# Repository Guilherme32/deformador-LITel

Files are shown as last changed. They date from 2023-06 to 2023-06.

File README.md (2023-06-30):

# Deformador do LITel

Esse repositório guarda o que foi desenvolvido de parte eletrônica / de código
do deformador do LITel.

# Informações

O deformador é um equipamento construído para aplicar uma deformação controlada
a uma placa de teste. A placa é afixada em uma extremidade, enquanto que a
outra é conectada a um cabo de aço que pode fazer uma força para baixo,
deformando o material com uma flecha. Um dinamômetro entre a placa e o cabo de
aço mede a força constantemente, para que o sistema possa ser usado para
calibração de sensores. O cabo de aço é puxado por um sistema com um motor de
passo e um fuso, controlado por um esp8266 através de duas interfaces
possíveis.

Embora o sistema tenha a possibilidade de visualização do movimento do fuso do
motor, é recomendado que se use apenas a força lida no dinamômetro para
calibração de sensores. Isso se dá porque a distância percorrida no fuso não
é igual à distância da flecha na placa, por conta dos componentes que estão no
meio do caminho.

# Interface Física

A interface mais simples de se usar é a física, composta de 7 botões. Com o
lado dos botões para cima, e o conector à esquerda, a função dos botões são,
seguindo da esquerda para a direita:

- Botão 1: Recua 5cm (alivia a carga);
- Botão 2: Recua 5mm (alivia a carga);
- Botão 3: Recua 1mm (alivia a carga);
- Botão 4: Interrompe o movimento;
- Botão 5: Avança 1mm (aumenta a carga);
- Botão 6: Avança 5mm (aumenta a carga);
- Botão 7: Avança 5cm (aumenta a carga);

Caso os botões sejam segurados, os comandos serão continuamente repetidos,
sendo que os valores são atualizados a partir do atual. Dessa forma, o sistema
irá iniciar o movimento ao pressionar o botão, e irá se mover pelo valor do
botão após ser soltado.

> Por exemplo, se o botão 3 for segurado por 2 segundos, e então solto, o
> sistema irá recuar continuamente por 2 segundos, e após isso ainda irá recuar
> mais 1mm.

Os botões mais extremos movem a flecha por valores consideravelmente grandes, e
foram feitos com o objetivo de colocar um alvo distante e de que os comandos
sejam interrompidos manualmente.

Com essa interface, não há como saber a distância percorrida no fuso do motor.

# Interface Web

Para o uso da interface web, é necessário o uso de um dispositivo que esteja
conectado à mesma rede local do esp8266 e seja capaz de renderizar páginas web
(HTML, CSS e JS). O esp possui a função de ponto de acesso, permitindo a
que o dispositivo se conecte diretamente a ele, caso possua conectividade WiFi.

## Ponto de Acesso (Access Point)

As credenciais de acesso do modo de ponto de acesso são as seguintes:

> SSID: deformador-litel
> Senha: 787Cu7kg

Nesse modo, o programa pode ser acessado através do ip:

> ip: 192.168.4.1

## Modo Estação (Station)

O esp também pode se conectar a uma rede externa. Isso aumenta a confiabilidade
do sistema, porque o ponto de acesso do esp não é muito estável. Para que ele
se conecte, é necessário que primeiro o dispositivo acesse o programa pelo
ponto de acesso, e então configure as credenciais da rede externa pela página
de conexão. Na página de conexão é possível ver o status (se conseguiu
conectar) e o endereço de ip.

Com o dispositivo conectado à mesma rede externa, o endereço ip do esp deverá
ser utilizado para acessar a aplicação.

> O esp tentará se conectar à última rede configurada sempre que for ligado.

## Páginas

### Página Principal

A página principal serve apenas como entrada à interface. Ela permite acesso às
outras páginas do sistema, e também tem o link do repositório no GitHub.

> Todas as páginas possuem os mesmos links presentes nessa.

### Conexão

Essa página mostra as informações de conexão (SSID, senha, ip), e permite mudar
as credenciais da rede a ser acessada pelo modo estação. Também indica se o
modo de estação está conectado devidamente.

### Controle

Essa página é a que permite a interface principal do sistema. Através daqui é
possível visualizar a posição atual do motor, o deslocamento correspondente no
fuso, e também enviar novos comandos para o sistema.

Os componentes importantes da página são:

- Comandos: É possível enviar dois comandos para o sistema:
  - Deslocar: Envia uma nova posição alvo para o deslocamento. Esse comando não
              é cumulativo, o valor enviado é o alvo, não um valor a mover;
  - Encontrar zero: Envia o comando de reset de zero. O sistema entrará na
                    sequência de detecção, não podendo receber outros comandos
                    e recuando (aliviando a carga) até que encontrar o sensor
                    de fim de curso;
- Informações: Algumas informações são dispostas no centro da página:
  - Progresso: Uma barra cresce da esquerda para a direita, indicando o
               progresso do último comando;
  - Estado: O estado do sistema, que pode ser "movendo", "parado" ou
            "procurando zero"
  - Posição: A posição e correspondente deslocamento atuais no fuso do motor.

> !! O DESLOCAMENTO NÃO DEVE SER USADO PARA CALIBRAÇÃO !! É possível calcular a
> deformação da placa a partir da flecha, mas não é trivial calcular a flecha
> a partir do deslocamento do fuso. Os deslocamentos não serão iguais, porque
> o cabo de aço, o dinamômetro e outros componentes no meio do caminho se
> deformam

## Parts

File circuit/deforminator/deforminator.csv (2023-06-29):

Source: | D:\espstuff\8266\msys32\home\guilh\esp8266\deforminator\circuit\deforminator\deforminator.kicad_sch
Date: | 14/06/2023 17:54:08
Tool: | Eeschema (6.0.5)
Generator: | D:\Programs\KiCad\6.0\bin\scripting\plugins/bom_csv_grouped_by_value.py
Component Count: | 21
Individual Components:
Item | Qty | Reference(s) | Value | LibPart | Footprint | Datasheet
 |  | A1 | Pololu_Breakout_DRV8825 | Driver_Motor:Pololu_Breakout_DRV8825 | Module:Pololu_Breakout-16_15.2x20.3mm | https://www.pololu.com/product/2982
 |  | D1 | LED | Device:LED | LED_THT:LED_D3.0mm_Clear | ~
 |  | D2 | LED | Device:LED | LED_THT:LED_D3.0mm_Clear | ~
 |  | D3 | LED | Device:LED | LED_THT:LED_D3.0mm_Clear | ~
 |  | J1 | Conn_01x04_Male | Connector:Conn_01x04_Male | Connector_PinHeader_2.54mm:PinHeader_1x04_P2.54mm_Vertical | ~
 |  | J2 | Conn_01x02_Male | Connector:Conn_01x02_Male | Connector_PinHeader_2.54mm:PinHeader_1x02_P2.54mm_Vertical | ~
 |  | J3 | Conn_01x02_Male | Connector:Conn_01x02_Male | Connector_PinHeader_2.54mm:PinHeader_1x02_P2.54mm_Vertical | ~
 |  | J4 | Conn_01x02_Male | Connector:Conn_01x02_Male | Connector_PinHeader_2.54mm:PinHeader_1x02_P2.54mm_Vertical | ~
 |  | J5 | Conn_01x02_Male | Connector:Conn_01x02_Male | Connector_PinHeader_2.54mm:PinHeader_1x02_P2.54mm_Vertical | ~
 |  | R1 | R | Device:R | Resistor_THT:R_Axial_DIN0207_L6.3mm_D2.5mm_P7.62mm_Horizontal | ~
 |  | R2 | R | Device:R | Resistor_THT:R_Axial_DIN0207_L6.3mm_D2.5mm_P7.62mm_Horizontal | ~
 |  | R3 | R | Device:R | Resistor_THT:R_Axial_DIN0207_L6.3mm_D2.5mm_P7.62mm_Horizontal | ~
 |  | R4 | R | Device:R | Resistor_THT:R_Axial_DIN0207_L6.3mm_D2.5mm_P7.62mm_Horizontal | ~
 |  | R5 | R | Device:R | Resistor_THT:R_Axial_DIN0207_L6.3mm_D2.5mm_P7.62mm_Horizontal | ~
 |  | R6 | R | Device:R | Resistor_THT:R_Axial_DIN0207_L6.3mm_D2.5mm_P7.62mm_Horizontal | ~
 |  | R7 | R | Device:R | Resistor_THT:R_Axial_DIN0207_L6.3mm_D2.5mm_P7.62mm_Horizontal | ~
 |  | R8 | R | Device:R | Resistor_THT:R_Axial_DIN0207_L6.3mm_D2.5mm_P7.62mm_Horizontal | ~
 |  | R9 | R | Device:R | Resistor_THT:R_Axial_DIN0207_L6.3mm_D2.5mm_P7.62mm_Horizontal | ~
 |  | SWreset1 | SW_Push | Switch:SW_Push | Button_Switch_THT:SW_PUSH_6mm | ~
 |  | SWreset2 | SW_Push | Switch:SW_Push | Button_Switch_THT:SW_PUSH_6mm | ~
 |  | U1 | ESP-12E | RF_Module:ESP-12E | RF_Module:ESP-12E | http://wiki.ai-thinker.com/_media/esp8266/esp8266_series_modules_user_manual_v1.1.pdf
Collated Components:
Item | Qty | Reference(s) | Value | LibPart | Footprint | Datasheet
1 | 1 | A1 | Pololu_Breakout_DRV8825 | Driver_Motor:Pololu_Breakout_DRV8825 | Module:Pololu_Breakout-16_15.2x20.3mm | https://www.pololu.com/product/2982
2 | 3 | D1, D2, D3 | LED | Device:LED | LED_THT:LED_D3.0mm_Clear | ~
3 | 1 | J1 | Conn_01x04_Male | Connector:Conn_01x04_Male | Connector_PinHeader_2.54mm:PinHeader_1x04_P2.54mm_Vertical | ~
4 | 4 | J2, J3, J4, J5 | Conn_01x02_Male | Connector:Conn_01x02_Male | Connector_PinHeader_2.54mm:PinHeader_1x02_P2.54mm_Vertical | ~
5 | 9 | R1, R2, R3, R4, R5, R6, R7, R8, R9 | R | Device:R | Resistor_THT:R_Axial_DIN0207_L6.3mm_D2.5mm_P7.62mm_Horizontal | ~
6 | 2 | SWreset1, SWreset2 | SW_Push | Switch:SW_Push | Button_Switch_THT:SW_PUSH_6mm | ~
7 | 1 | U1 | ESP-12E | RF_Module:ESP-12E | RF_Module:ESP-12E | http://wiki.ai-thinker.com/_media/esp8266/esp8266_series_modules_user_manual_v1.1.pdf

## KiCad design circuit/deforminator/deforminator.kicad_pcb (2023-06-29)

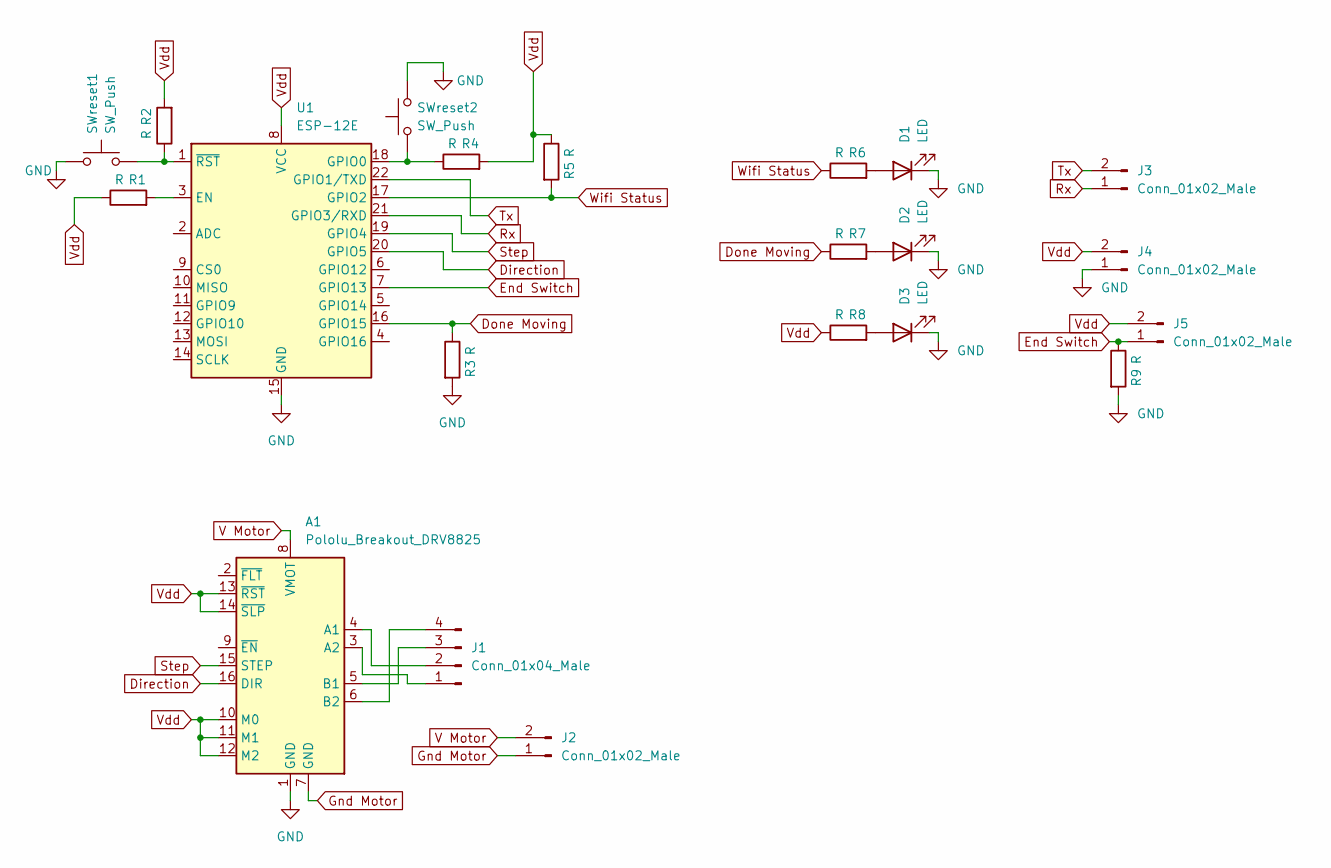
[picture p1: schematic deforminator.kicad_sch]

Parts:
A1: Pololu_Breakout_DRV8825; Pololu_Breakout-16_15.2x20.3mm
D1, D2, D3: LED; LED_D3.0mm_Clear
J1: Conn_01x04_Male; PinHeader_1x04_P2.54mm_Vertical
J2, J3, J4, J5: Conn_01x02_Male; PinHeader_1x02_P2.54mm_Vertical
R1, R2, R3, R4, R5, R6, R7, R8, R9: R; R_Axial_DIN0207_L6.3mm_D2.5mm_P7.62mm_Horizontal
SWreset1, SWreset2: SW_Push; SW_PUSH_6mm
U1: ESP-12E

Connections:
Direction: A1.16 (DIR), U1.20 (GPIO5)
Done Moving: R3.1, R7.1, U1.16 (GPIO15)
End Switch: J5.1, R9.1, U1.7 (GPIO13)
GND: A1.1 (GND), D1.1 (K), D2.1 (K), D3.1 (K), J4.1, R3.2, R9.2, SWreset1.1, SWreset2.2, U1.15 (GND)
Gnd Motor: A1.7 (GND), J2.1
unnamed: A1.3 (A2), J1.1
unnamed: A1.4 (A1), J1.2
unnamed: A1.5 (B1), J1.3
unnamed: A1.6 (B2), J1.4
unnamed: D3.2 (A), R8.2
unnamed: R1.2, U1.3 (EN)
unnamed: R2.1, SWreset1.2, U1.1 (~RST)
unnamed: R4.1, SWreset2.1, U1.18 (GPIO0)
unnamed: D1.2 (A), R6.2
unnamed: D2.2 (A), R7.2
Rx: J3.1, U1.21 (GPIO3/RXD)
Step: A1.15 (STEP), U1.19 (GPIO4)
Tx: J3.2, U1.22 (GPIO1/TXD)
V Motor: A1.8 (VMOT), J2.2
Vdd: A1.10 (M0), A1.11 (M1), A1.12 (M2), A1.13 (~RST), A1.14 (~SLP), J4.2, J5.2, R1.1, R2.2, R4.2, R5.1, R8.1, U1.8 (VCC)
Wifi Status: R5.2, R6.1, U1.17 (GPIO2)

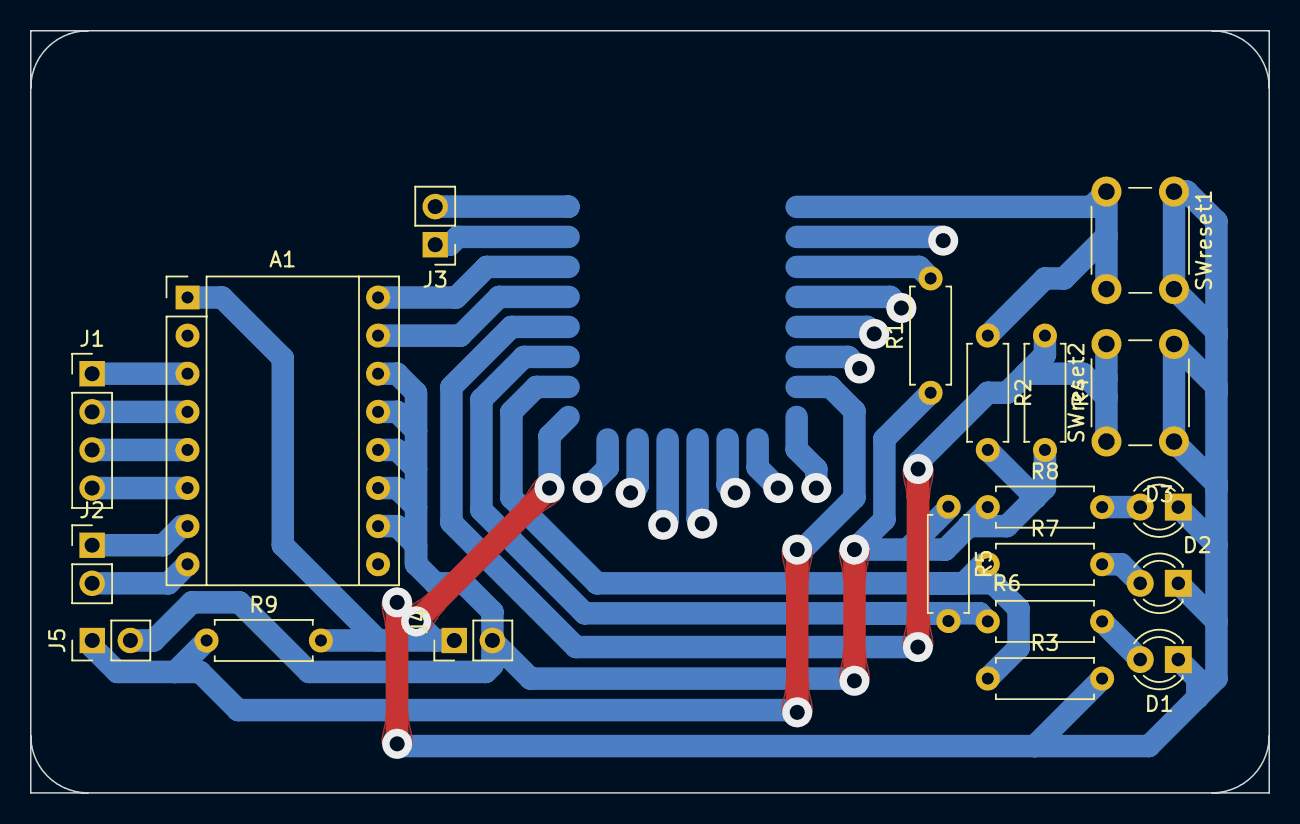
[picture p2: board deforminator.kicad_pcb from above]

Board: 2 copper layers, 82.6 x 50.8 mm, 21 parts (1 on the bottom side), 21 nets.

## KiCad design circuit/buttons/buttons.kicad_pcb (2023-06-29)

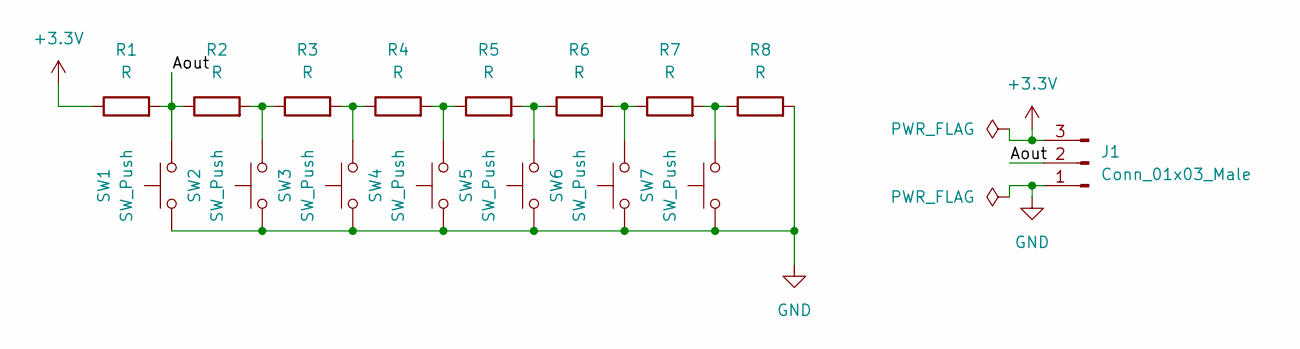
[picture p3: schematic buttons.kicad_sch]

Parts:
J1: Conn_01x03_Male; PinHeader_1x03_P2.54mm_Vertical
R1, R2, R3, R4, R5, R6, R7, R8: R; R_Axial_DIN0207_L6.3mm_D2.5mm_P7.62mm_Horizontal
SW1, SW2, SW3, SW4, SW5, SW6, SW7: SW_Push; SW_PUSH-12mm

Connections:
+3V3: J1.3, R1.1
/Aout: J1.2, R1.2, R2.1, SW1.2
GND: J1.1, R8.2, SW1.1, SW2.1, SW3.1, SW4.1, SW5.1, SW6.1, SW7.1
unnamed: R2.2, R3.1, SW2.2
unnamed: R3.2, R4.1, SW3.2
unnamed: R4.2, R5.1, SW4.2
unnamed: R5.2, R6.1, SW5.2
unnamed: R6.2, R7.1, SW6.2
unnamed: R7.2, R8.1, SW7.2

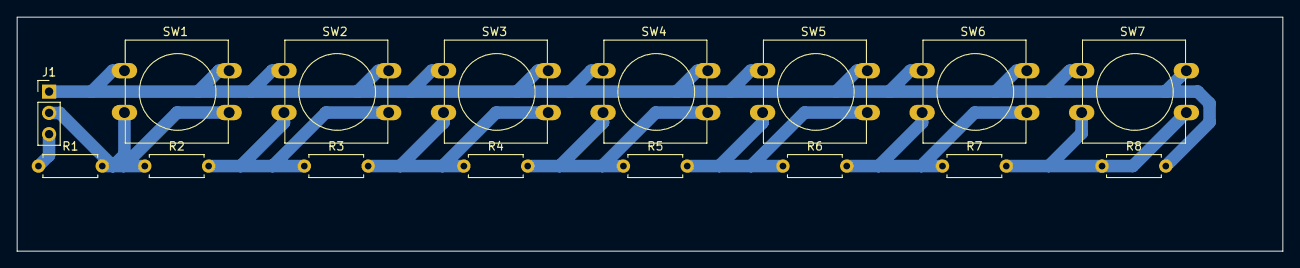
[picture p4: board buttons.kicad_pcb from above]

Board: 2 copper layers, 151.1 x 27.9 mm, 16 parts (0 on the bottom side), 9 nets.

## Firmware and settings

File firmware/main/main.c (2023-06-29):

/* Deformador do LITel
* O controle e interface do sistema foram desenvolvidos sobre um esp8266, e
* aqui esta o codigo do seu firmware. Mais informacoes do sistema podem ser
* obtidas no github: https://github.com/Guilherme32/deformador-LITel
*/


#include <stdio.h>
#include "freertos/FreeRTOS.h"
#include "freertos/task.h"
#include "esp_system.h"
#include "esp_spi_flash.h"
#include "esp_log.h"

#include "wifi.h"
#include "server.h"
#include "storage_spiffs.h"
#include "controller.h"
#include "serial_comm.h"


void app_main()
{
    // Some system info print -------------------------------------------------
    print_header();
    ESP_LOGI("STARTUP", "Starting up the system");

    // Modules init -----------------------------------------------------------
    wifi_init();
    spiffs_init();
    server_init(10);
    controller_init();
    serial_comm_init();

    // Linking modules --------------------------------------------------------
    add_command(netinfo_command, netinfo_command_help);

    // Starting modules tasks -------------------------------------------------
    xTaskCreate(wifi_led_task,
        "wifi_led_task",
        2*configMINIMAL_STACK_SIZE,
        NULL,
        10,
        NULL);

    xTaskCreate(serial_comm_task,
        "serial_task",
        2*configMINIMAL_STACK_SIZE,
        NULL,
        10,
        NULL);

    xTaskCreate(poll_buttons,
        "poll_buttons",
        2*configMINIMAL_STACK_SIZE,
        NULL,
        10,
        NULL);

}

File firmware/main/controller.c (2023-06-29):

#include "controller.h"
#include "helpers.h"

// Internal definitions ---------------------------------------------------------------------------

#define END_SWITCH_PIN 13
#define INPUT_PINS_FLAG (1ULL << END_SWITCH_PIN)

#define DIRECTION_PIN 5
#define STEP_PIN 4
#define DONE_MOVING_PIN 15
#define OUTPUT_PINS_FLAG   ( (1ULL << DIRECTION_PIN) \
                           | (1ULL << DONE_MOVING_PIN) \
                           | (1ULL << STEP_PIN) )

// Period = 400 us, pps = 2500
#define STEP_HALF_PERIOD_US 200

#define CONTROLLER_TAG "CONTROLLER"

#define DIR_PULL 0
#define DIR_PUSH 1

#define MULTISAMPLING 16

// ------------------------------------------------------------------------------------------------

static int target = 0;
static int real_position = 0;
static bool done_moving = 0;

static bool finding_zero = false;
static bool step_pulse_value = false;

// ------------------------------------------------------------------------------------------------

void step_to_find_zero() {
    if (step_pulse_value == 1) {
        if (gpio_get_level(END_SWITCH_PIN) == 1) {
            target = 0;
            real_position = 0;
            finding_zero = false;
            hw_timer_enable(false);
        }

        step_pulse_value = 0;
    } else {
        gpio_set_level(DIRECTION_PIN, DIR_PUSH);
        step_pulse_value = 1;
    }

    gpio_set_level(STEP_PIN, step_pulse_value);
}

void try_step(void* arg) {
    if (finding_zero) {
        step_to_find_zero();
        return;
    }

    if (step_pulse_value == 1) {
        if (target == real_position) {
            hw_timer_enable(false);
            done_moving = true;
            gpio_set_level(DONE_MOVING_PIN, 1);
            return;
        }

        step_pulse_value = 0;
    } else {
        if (target > real_position) {
            gpio_set_level(DIRECTION_PIN, DIR_PULL);
            real_position ++;
        } else {
            gpio_set_level(DIRECTION_PIN, DIR_PUSH);
            real_position --;
        }

        step_pulse_value = 1;
    }

    gpio_set_level(STEP_PIN, step_pulse_value);
}

// Buttons ---------------------------------------
void buttons_init() {
    adc_config_t adc_config;
    adc_config.mode = ADC_READ_TOUT_MODE;
    adc_config.clk_div = 16;
    ESP_ERROR_CHECK(adc_init(&adc_config));
}

unsigned int read_button() {
    unsigned int mean = 0;
    unsigned int raw_reading = 0;

    for (int i=0; i<MULTISAMPLING; i++) {
        adc_read(&raw_reading);
        mean += raw_reading;
    }
    mean /= MULTISAMPLING;

    return mean;
}

void act_button(unsigned int reading) {
    // Expected values: 0, 152, 290, 417, 535, 643, 743, 836
    if (reading < 75) {
        set_target(real_position - 1600 * 50);       // -50mm
    }
    else if (reading < 225) {
        set_target(real_position - 1600 * 5);        // -5mm
    }
    else if (reading < 350) {
        set_target(real_position - 1600);            // -1mm
    }
    else if (reading < 475) {
        set_target(real_position);                   // stop
    }
    else if (reading < 590) {
        set_target(real_position + 1600);            // +1mm
    }
    else if (reading < 690) {
        set_target(real_position + 1600 * 5);        // -5mm
    }
    else if (reading < 790) {
        set_target(real_position + 1600 * 50);        // +50mm
    }
}

// Public ----------------------------------------------------------------------

void set_target(unsigned int _target) {
    if (target == _target) {
        return;
    }

    target = _target;

    done_moving = false;
    gpio_set_level(DONE_MOVING_PIN, 0);
    hw_timer_enable(true);
}

void reset_zero() {
    finding_zero = true;
    hw_timer_enable(true);
}

ControllerInfo get_info() {
    ControllerInfo info;
    info.state = finding_zero ? 2 : !done_moving;
    info.real_position = real_position;
    info.target_position = target;

    return info;
}

void poll_buttons() {
    while (1) {
        // printf("%u\n", read_button());
        act_button(read_button());
        vTaskDelay(100 / portTICK_PERIOD_MS);
    }
}

void controller_init()
{
    gpio_config_t gpio_cfg;                                // Init output and stability pins
    gpio_cfg.intr_type = GPIO_INTR_DISABLE;
    gpio_cfg.mode = GPIO_MODE_OUTPUT;
    gpio_cfg.pin_bit_mask = OUTPUT_PINS_FLAG;
    gpio_cfg.pull_down_en = 0;
    gpio_cfg.pull_up_en = 0;
    gpio_config(&gpio_cfg);

    gpio_set_level(DIRECTION_PIN, 0);
    gpio_set_level(STEP_PIN, 0);
    gpio_set_level(DONE_MOVING_PIN, 0);


    gpio_config_t inputs_cfg;                                // Inputs interrupt
    inputs_cfg.intr_type = GPIO_INTR_DISABLE;
    inputs_cfg.pin_bit_mask = INPUT_PINS_FLAG;
    inputs_cfg.mode = GPIO_MODE_INPUT;
    inputs_cfg.pull_up_en = 0;
    inputs_cfg.pull_down_en = 0;
    gpio_config(&inputs_cfg);

    // Step timer -------------------------------------------------------------

    hw_timer_init(try_step, NULL);
    hw_timer_set_clkdiv(TIMER_CLKDIV_1);
    hw_timer_set_intr_type(TIMER_EDGE_INT);
    hw_timer_set_reload(true);
    hw_timer_set_load_data(STEP_HALF_PERIOD_US * (TIMER_BASE_CLK / 1000000));    // TODO check
    hw_timer_enable(false);

    // buttons ------------------
    buttons_init();

    ESP_LOGI(CONTROLLER_TAG, "Initiated the controller");

}
